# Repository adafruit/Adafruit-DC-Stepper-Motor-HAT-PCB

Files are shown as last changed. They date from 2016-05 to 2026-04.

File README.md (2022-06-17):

## Adafruit DC Stepper Motor HAT and Bonnet PCB
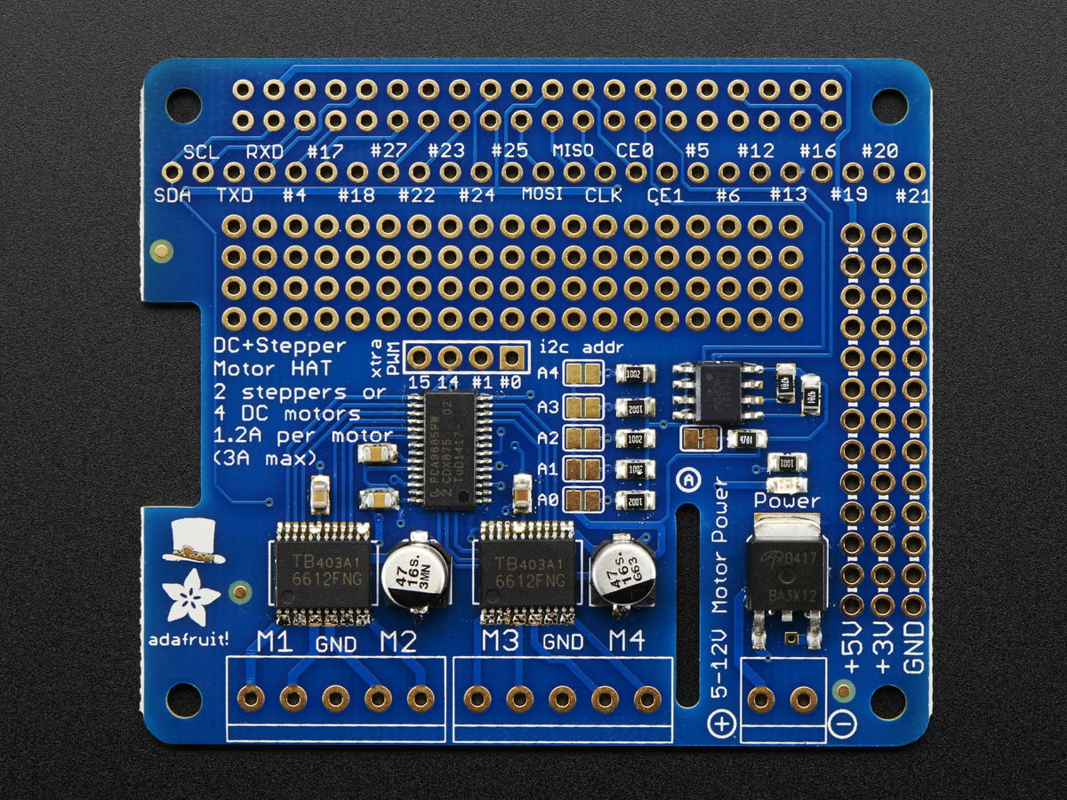
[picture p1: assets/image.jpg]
<a href="http://www.adafruit.com/products/2348"><br/>
Click here to purchase one from the Adafruit shop</a>

Let your robotic dreams come true with the new DC+Stepper Motor HAT from Adafruit. This Raspberry Pi add-on is perfect for any motion project as it can drive up to 4 DC or 2 Stepper motors with full PWM speed control.

Raspberry Pi and motors are not included. Works with any and all Raspberry Pi computers with 2x20 connection port.

Since the Raspberry Pi does not have a lot of PWM pins, we use a fully-dedicated PWM driver chip onboard to both control motor direction and speed. This chip handles all the motor and speed controls over I2C. Only two pins (SDA & SCL) are required to drive the multiple motors, and since it's I2C you can also connect any other I2C devices or HATs to the same pins.

In fact, you can even stack multiple Motor HATs, up to 32 of them, for controlling up to 64 stepper motors or 128 DC motors (or a mix of the two) - just remember to purchase and solder in a stacking header instead of the one we include.

Motors are controlled by TB6612 MOSFET drivers with 1.2A per channel current capability (you can draw up to 3A peak for approx 20ms at a time), a big improvement over L293D drivers and there are built-in flyback diodes as well.

PCB files for the Adafruit DC Stepper Motor Hat and Bonnet. The format is EagleCAD schematic and board layout
- https://www.adafruit.com/products/2348
- https://www.adafruit.com/product/4280

### License

Adafruit invests time and resources providing this open source design, please support Adafruit and open-source hardware by purchasing products from [Adafruit](https://www.adafruit.com)!

All text above must be included in any redistribution

Designed by Limor Fried/Ladyada for Adafruit Industries.
Creative Commons Attribution/Share-Alike, all text above must be included in any redistribution. 
See license.txt for additional information.

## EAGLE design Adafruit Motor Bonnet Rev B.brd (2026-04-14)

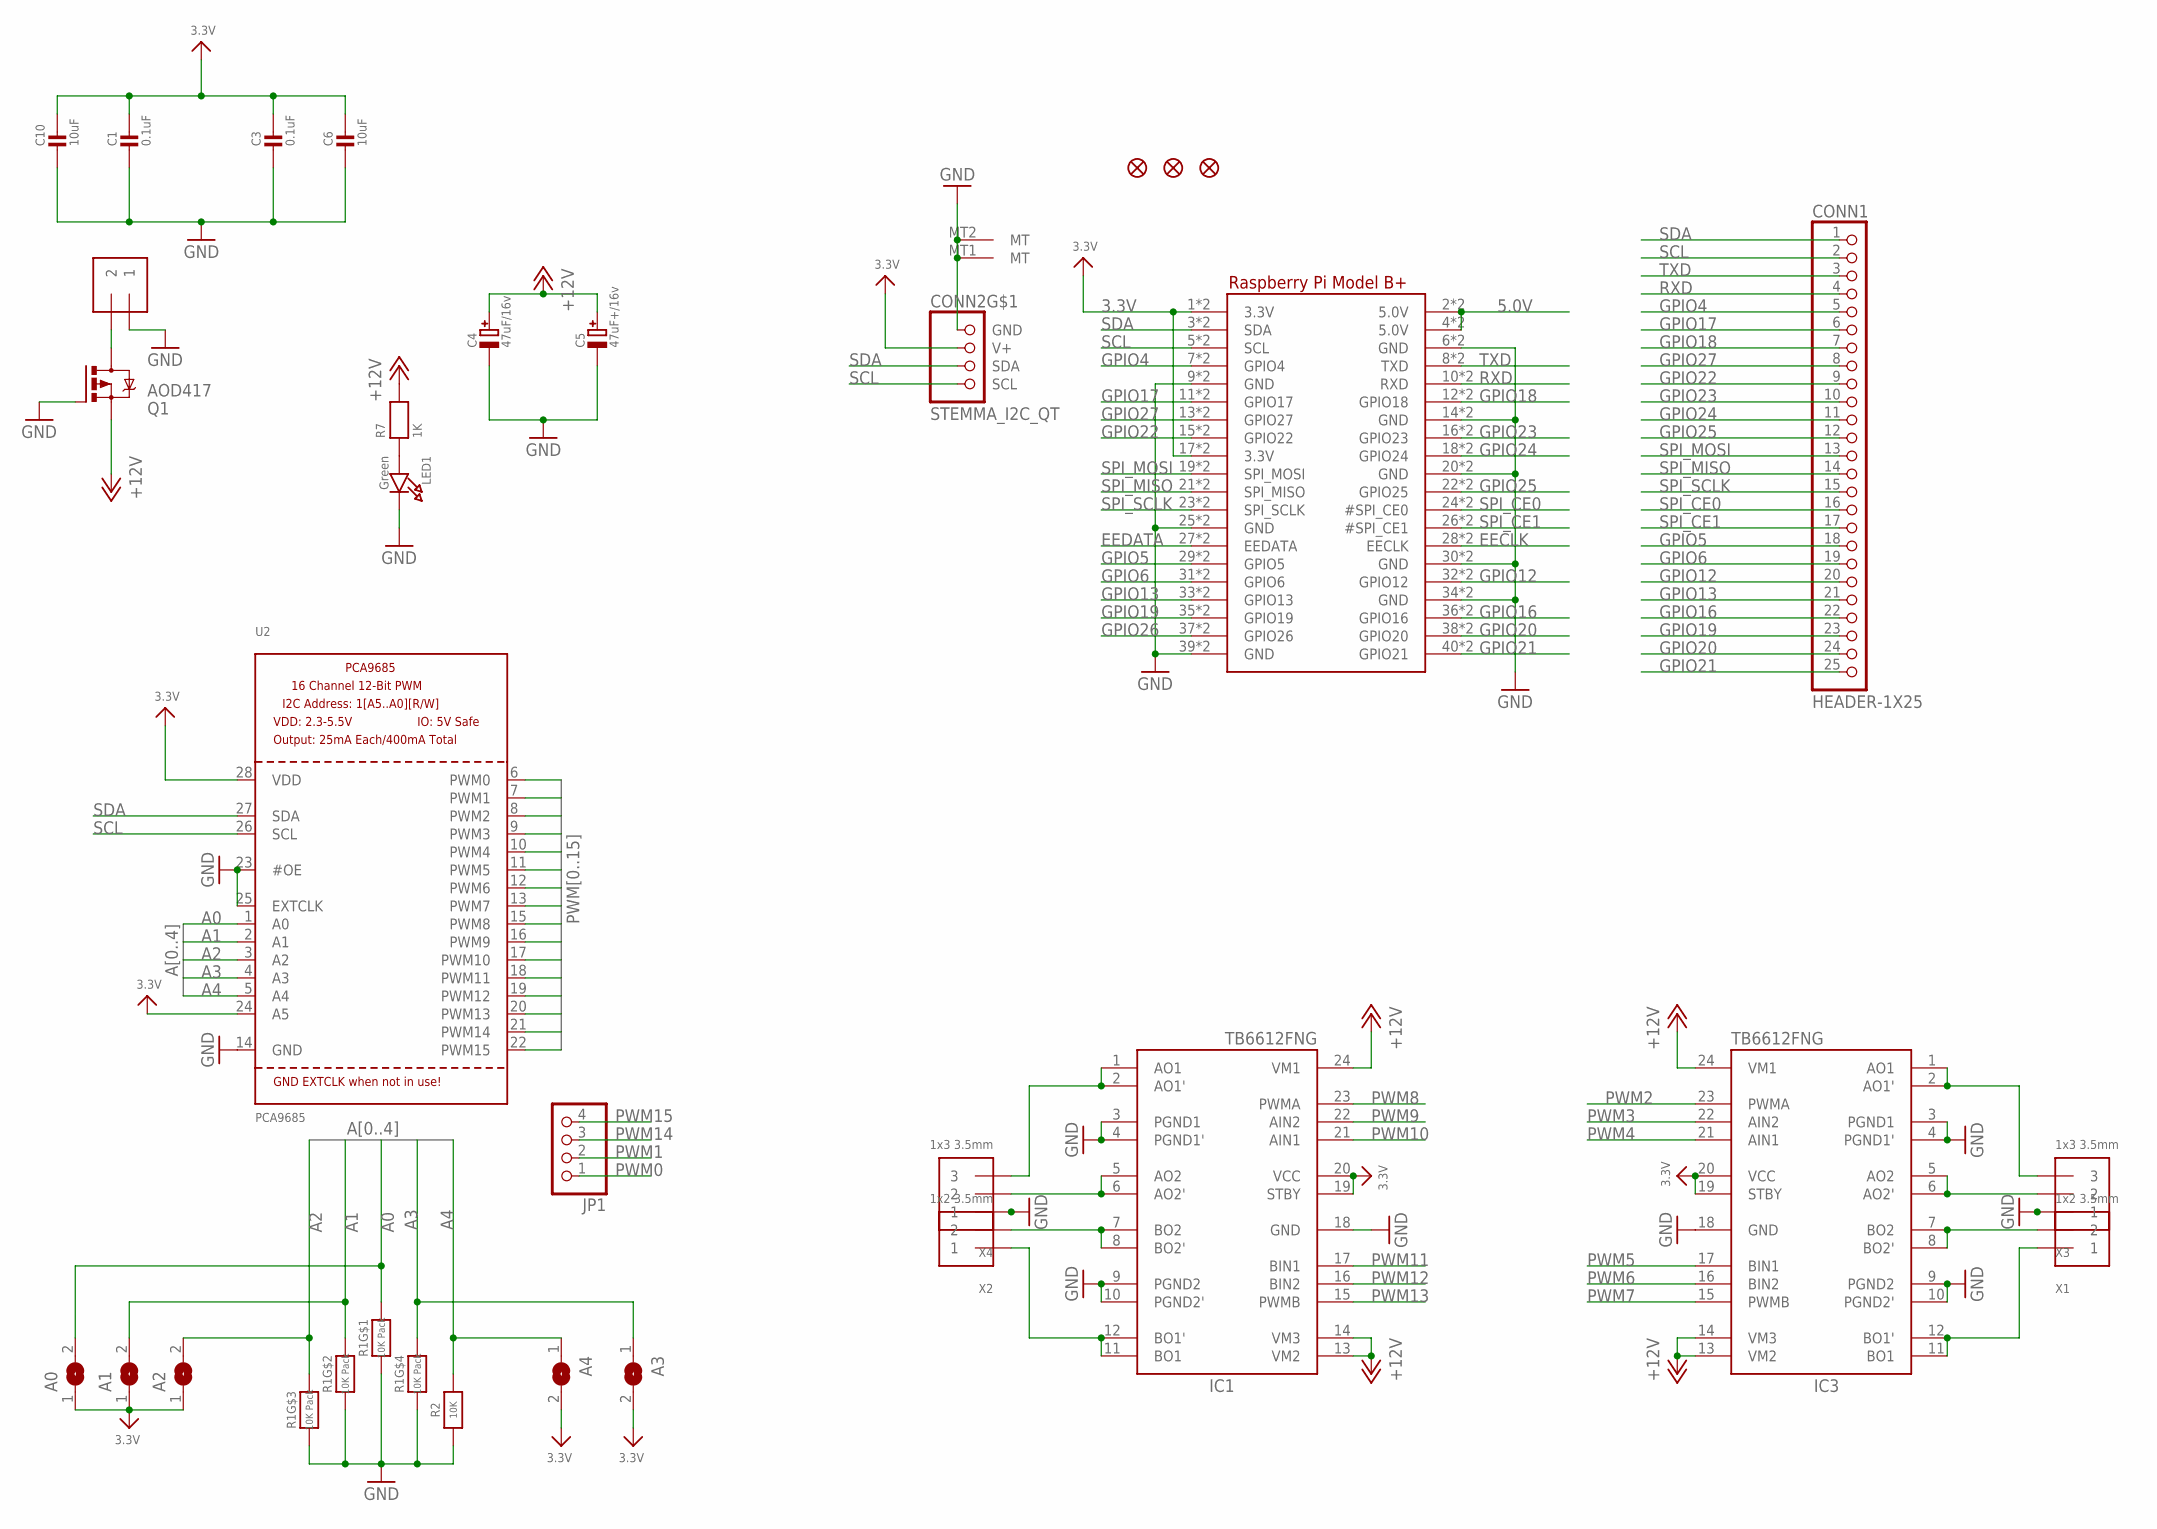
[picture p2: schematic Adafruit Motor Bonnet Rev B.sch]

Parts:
A0, A1, A2, A3, A4: SOLDERJUMPERREFLOW_NOPASTE; SOLDERJUMPER_REFLOW_NOPASTE
C1, C3: 0.1uF; 0603-NO
C4: 47uF/16v; PANASONIC_C
C5: 47uF+/16v; PANASONIC_C
C6, C10: 10uF; 0805-NO
CONN1: HEADER-1X25; 1X25_ROUND_70MIL
CONN2: STEMMA_I2C_QT; JST_SH4
FID1, FID2, FID3: FIDUCIAL_1MM
IC1, IC3: TB6612FNG; SSOP24
JP1: HEADER-1X4ROUND; 1X04_ROUND
LED1: Green; CHIPLED_0805_NOOUTLINE
MPOWER: 1x2 3.5mm; TERMBLOCK_1X2-3.5MM
Q1: AOD417; D-PAK_TO252AA
R1: 10K Pack; RESPACK_4X0603
R2: 10K; 0603-NO
R7: 1K; 0603-NO
RPI1: RASPBERRYPI_BPLUS_BONNET_THMSMT; PI_BONNET_THMSMT
U2: PCA9685; TSSOP28
X1, X2: 1x2 3.5mm; TERMBLOCK_1X2-3.5MM
X3, X4: 1x3 3.5mm; TERMBLOCK_1X3-3.5MM

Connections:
3.3V: A0.1, A1.1, A2.1, A3.2, A4.2, C1.1, C3.1, C6.1, C10.1, CONN2.2 (V+), IC1.19 (STBY), IC1.20 (VCC), IC3.19 (STBY), IC3.20 (VCC), RPI1.1 (3.3V), RPI1.17 (3.3V), RPI1.S1 (3.3V), RPI1.S17 (3.3V), U2.24 (A5), U2.28 (VDD)
5.0V: RPI1.2 (5.0V), RPI1.4 (5.0V), RPI1.S2 (5.0V), RPI1.S4 (5.0V)
+12V: C4.+, C5.+, IC1.13 (VM2), IC1.14 (VM3), IC1.24 (VM1), IC3.13 (VM2), IC3.14 (VM3), IC3.24 (VM1), Q1.3 (S), R7.2
A0: A0.2, R1.8 (2), U2.1 (A0)
A1: A1.2, R1.7 (2), U2.2 (A1)
A2: A2.2, R1.6 (2), U2.3 (A2)
A3: A3.1, R1.5 (2), U2.4 (A3)
A4: A4.1, R2.2, U2.5 (A4)
EECLK: RPI1.28 (EECLK), RPI1.S28 (EECLK)
EEDATA: RPI1.27 (EEDATA), RPI1.S27 (EEDATA)
GND: C1.2, C3.2, C4.-, C5.-, C6.2, C10.2, CONN2.1 (GND), CONN2.MT1 (MT), CONN2.MT2 (MT), IC1.3 (PGND1), IC1.4 (PGND1'), IC1.9 (PGND2), IC1.10 (PGND2'), IC1.18 (GND), IC3.3 (PGND1), IC3.4 (PGND1'), IC3.9 (PGND2), IC3.10 (PGND2'), IC3.18 (GND), LED1.C, MPOWER.1, Q1.1 (G), R1.1, R1.2 (1), R1.3 (1), R1.4 (1), R2.1, RPI1.6 (GND), RPI1.9 (GND), RPI1.14 (GND), RPI1.20 (GND), RPI1.25 (GND), RPI1.30 (GND), RPI1.34 (GND), RPI1.39 (GND), RPI1.S6 (GND), RPI1.S9 (GND), RPI1.S14 (GND), RPI1.S20 (GND), RPI1.S25 (GND), RPI1.S30 (GND), RPI1.S34 (GND), RPI1.S39 (GND), U2.14 (GND), U2.23 (#OE), U2.25 (EXTCLK), X3.1, X4.1
GPIO4: CONN1.5, RPI1.7 (GPIO4), RPI1.S7 (GPIO4)
GPIO5: CONN1.18, RPI1.29 (GPIO5), RPI1.S29 (GPIO5)
GPIO6: CONN1.19, RPI1.31 (GPIO6), RPI1.S31 (GPIO6)
GPIO12: CONN1.20, RPI1.32 (GPIO12), RPI1.S32 (GPIO12)
GPIO13: CONN1.21, RPI1.33 (GPIO13), RPI1.S33 (GPIO13)
GPIO16: CONN1.22, RPI1.36 (GPIO16), RPI1.S36 (GPIO16)
GPIO17: CONN1.6, RPI1.11 (GPIO17), RPI1.S11 (GPIO17)
GPIO18: CONN1.7, RPI1.12 (GPIO18), RPI1.S12 (GPIO18)
GPIO19: CONN1.23, RPI1.35 (GPIO19), RPI1.S35 (GPIO19)
GPIO20: CONN1.24, RPI1.38 (GPIO20), RPI1.S38 (GPIO20)
GPIO21: CONN1.25, RPI1.40 (GPIO21), RPI1.S40 (GPIO21)
GPIO22: CONN1.9, RPI1.15 (GPIO22), RPI1.S15 (GPIO22)
GPIO23: CONN1.10, RPI1.16 (GPIO23), RPI1.S16 (GPIO23)
GPIO24: CONN1.11, RPI1.18 (GPIO24), RPI1.S18 (GPIO24)
GPIO25: CONN1.12, RPI1.22 (GPIO25), RPI1.S22 (GPIO25)
GPIO26: RPI1.37 (GPIO26), RPI1.S37 (GPIO26)
GPIO27: CONN1.8, RPI1.13 (GPIO27), RPI1.S13 (GPIO27)
M1A: IC1.1 (AO1), IC1.2 (AO1'), X4.3
M1B: IC1.5 (AO2), IC1.6 (AO2'), X4.2
M2A: IC1.11 (BO1), IC1.12 (BO1'), X2.1
M2B: IC1.7 (BO2), IC1.8 (BO2'), X2.2
M3A: IC3.1 (AO1), IC3.2 (AO1'), X3.3
M3B: IC3.5 (AO2), IC3.6 (AO2'), X3.2
M4A: IC3.11 (BO1), IC3.12 (BO1'), X1.1
M4B: IC3.7 (BO2), IC3.8 (BO2'), X1.2
unnamed: LED1.A, R7.1
PWM0: JP1.1, U2.6 (PWM0)
PWM1: JP1.2, U2.7 (PWM1)
PWM2: IC3.23 (PWMA), U2.8 (PWM2)
PWM3: IC3.22 (AIN2), U2.9 (PWM3)
PWM4: IC3.21 (AIN1), U2.10 (PWM4)
PWM5: IC3.17 (BIN1), U2.11 (PWM5)
PWM6: IC3.16 (BIN2), U2.12 (PWM6)
PWM7: IC3.15 (PWMB), U2.13 (PWM7)
PWM8: IC1.23 (PWMA), U2.15 (PWM8)
PWM9: IC1.22 (AIN2), U2.16 (PWM9)
PWM10: IC1.21 (AIN1), U2.17 (PWM10)
PWM11: IC1.17 (BIN1), U2.18 (PWM11)
PWM12: IC1.16 (BIN2), U2.19 (PWM12)
PWM13: IC1.15 (PWMB), U2.20 (PWM13)
PWM14: JP1.3, U2.21 (PWM14)
PWM15: JP1.4, U2.22 (PWM15)
RXD: CONN1.4, RPI1.10 (RXD), RPI1.S10 (RXD)
SCL: CONN1.2, CONN2.4 (SCL), RPI1.5 (SCL), RPI1.S5 (SCL), U2.26 (SCL)
SDA: CONN1.1, CONN2.3 (SDA), RPI1.3 (SDA), RPI1.S3 (SDA), U2.27 (SDA)
SPI_CE0: CONN1.16, RPI1.24 (#SPI_CE0), RPI1.S24 (#SPI_CE0)
SPI_CE1: CONN1.17, RPI1.26 (#SPI_CE1), RPI1.S26 (#SPI_CE1)
SPI_MISO: CONN1.14, RPI1.21 (SPI_MISO), RPI1.S21 (SPI_MISO)
SPI_MOSI: CONN1.13, RPI1.19 (SPI_MOSI), RPI1.S19 (SPI_MOSI)
SPI_SCLK: CONN1.15, RPI1.23 (SPI_SCLK), RPI1.S23 (SPI_SCLK)
TXD: CONN1.3, RPI1.8 (TXD), RPI1.S8 (TXD)
VMOTOR: MPOWER.2, Q1.4 (D)

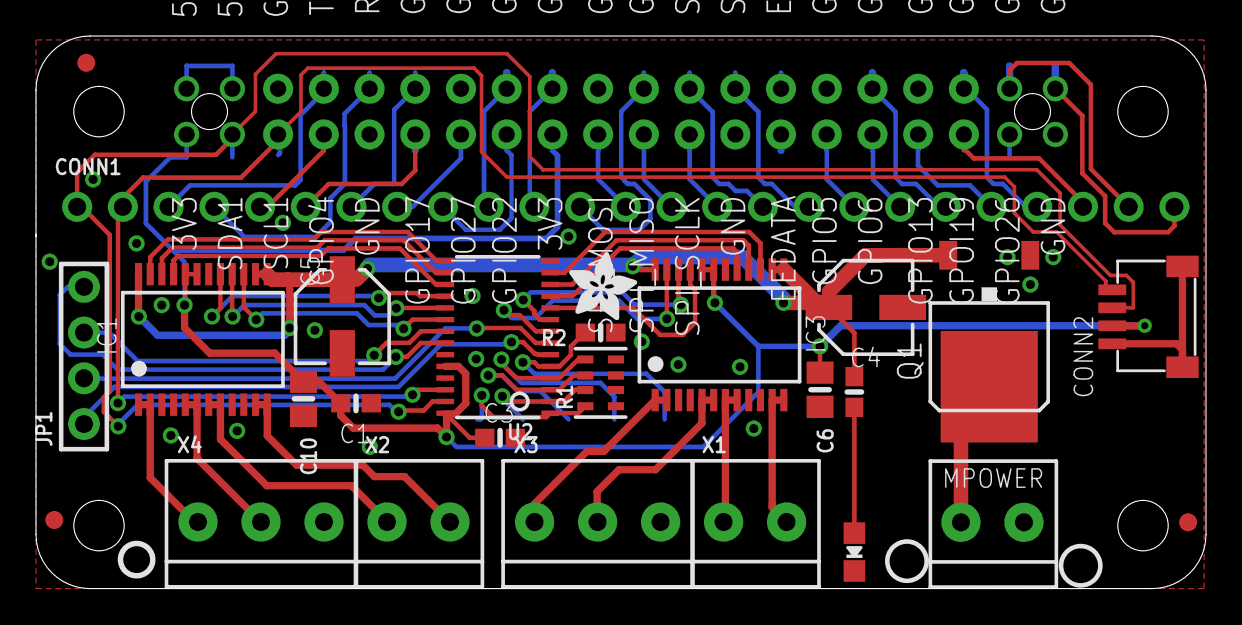
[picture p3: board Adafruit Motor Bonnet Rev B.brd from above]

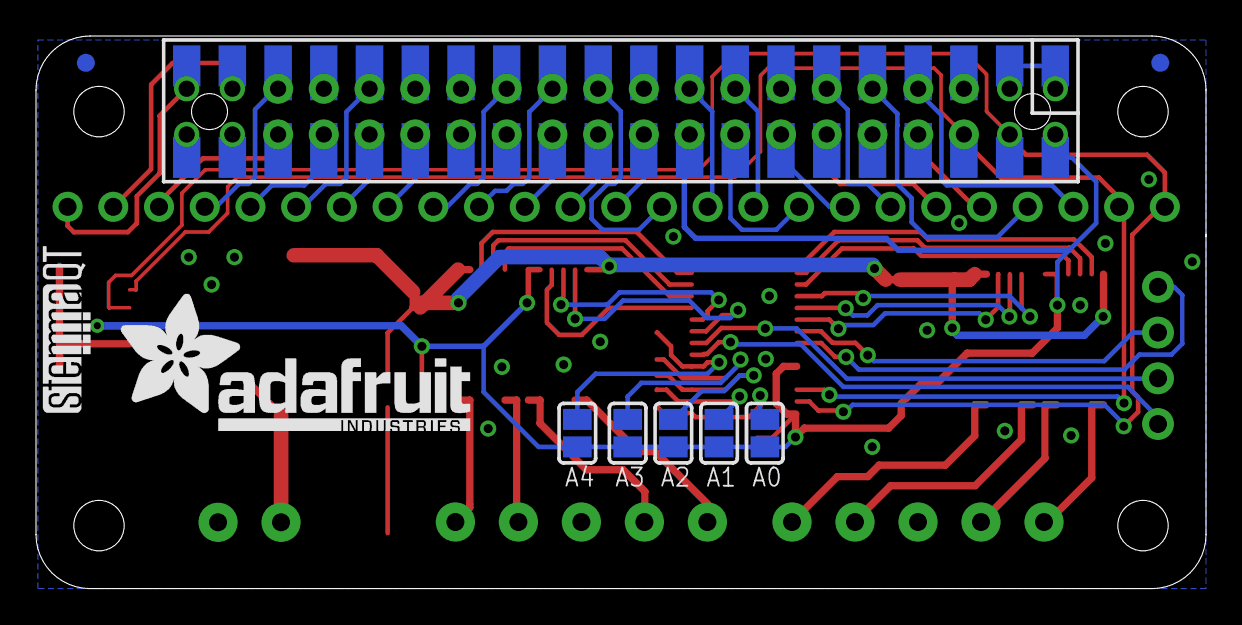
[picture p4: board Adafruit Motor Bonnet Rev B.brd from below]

Board: 2 copper layers, 65.0 x 30.7 mm, 82 parts (13 on the bottom side), 63 nets.

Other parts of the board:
PLABEL0: PLABEL0
PLABEL1: PLABEL1
PLABEL2: PLABEL2
PLABEL3: PLABEL3
PLABEL4: PLABEL4
PLABEL5: PLABEL5
PLABEL6: PLABEL6
PLABEL7: PLABEL7
PLABEL8: PLABEL8
PLABEL9: PLABEL9
PLABEL10: PLABEL10
PLABEL11: PLABEL11
PLABEL12: PLABEL12
PLABEL13: PLABEL13
PLABEL14: PLABEL14
PLABEL15: PLABEL15
PLABEL16: PLABEL16
PLABEL17: PLABEL17
PLABEL18: PLABEL18
PLABEL19: PLABEL19
PLABEL20: PLABEL20
PLABEL21: PLABEL21
PLABEL22: PLABEL22
PLABEL23: PLABEL23
PLABEL24: PLABEL24
PLABEL25: PLABEL25
PLABEL26: PLABEL26
PLABEL27: PLABEL27
PLABEL28: PLABEL28
PLABEL29: PLABEL29
PLABEL30: PLABEL30
PLABEL31: PLABEL31
PLABEL33: PLABEL33
PLABEL34: PLABEL34
PLABEL35: PLABEL35
PLABEL36: PLABEL36
PLABEL37: PLABEL37
PLABEL38: PLABEL38
PLABEL39: PLABEL39
PLABEL40: PLABEL40
PLABEL41: PLABEL41
PLABEL42: PLABEL42
PLABEL43: PLABEL43
PLABEL44: PLABEL44
PLABEL45: PLABEL45
PLABEL46: PLABEL46
PLABEL47: PLABEL47
U$6: PCBFEAT-REV-040
U$8: ADAFRUIT_TEXT_20MM
U$14: ADAFRUIT_3.5MM
U$15: STEMMAQT

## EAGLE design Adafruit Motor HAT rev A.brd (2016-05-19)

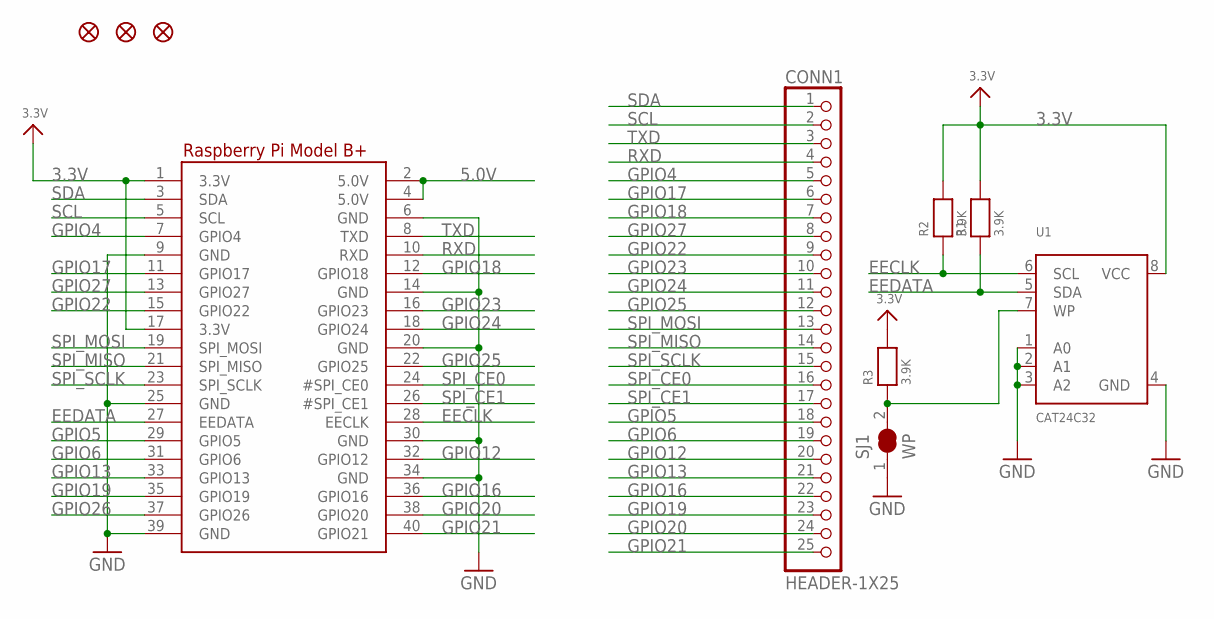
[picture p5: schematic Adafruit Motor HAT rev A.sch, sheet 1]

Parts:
CONN1: HEADER-1X25; 1X25_ROUND_70MIL
FID1, FID2, FID3: FIDUCIAL""; FIDUCIAL_1MM
R1, R2, R3: 3.9K; 0805-NO
RPI1: RASPBERRYPI_BPLUS_HATSLOTS; PI_HAT_SLOTS
SJ1: WP; SOLDERJUMPER_CLOSEDWIRE
U1: CAT24C32; SOIC8_150MIL

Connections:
3.3V: R1.2, R2.2, R3.2, RPI1.1 (3.3V), RPI1.17 (3.3V), U1.8 (VCC); also elsewhere on the board
5.0V: RPI1.2 (5.0V), RPI1.4 (5.0V)
EECLK: R2.1, RPI1.28 (EECLK), U1.6 (SCL)
EEDATA: R1.1, RPI1.27 (EEDATA), U1.5 (SDA)
GND: RPI1.6 (GND), RPI1.9 (GND), RPI1.14 (GND), RPI1.20 (GND), RPI1.25 (GND), RPI1.30 (GND), RPI1.34 (GND), RPI1.39 (GND), SJ1.1, U1.1 (A0), U1.2 (A1), U1.3 (A2), U1.4 (GND); also elsewhere on the board
GPIO4: CONN1.5, RPI1.7 (GPIO4)
GPIO5: CONN1.18, RPI1.29 (GPIO5)
GPIO6: CONN1.19, RPI1.31 (GPIO6)
GPIO12: CONN1.20, RPI1.32 (GPIO12)
GPIO13: CONN1.21, RPI1.33 (GPIO13)
GPIO16: CONN1.22, RPI1.36 (GPIO16)
GPIO17: CONN1.6, RPI1.11 (GPIO17)
GPIO18: CONN1.7, RPI1.12 (GPIO18)
GPIO19: CONN1.23, RPI1.35 (GPIO19)
GPIO20: CONN1.24, RPI1.38 (GPIO20)
GPIO21: CONN1.25, RPI1.40 (GPIO21)
GPIO22: CONN1.9, RPI1.15 (GPIO22)
GPIO23: CONN1.10, RPI1.16 (GPIO23)
GPIO24: CONN1.11, RPI1.18 (GPIO24)
GPIO25: CONN1.12, RPI1.22 (GPIO25)
GPIO26: RPI1.37 (GPIO26)
GPIO27: CONN1.8, RPI1.13 (GPIO27)
unnamed: R3.1, SJ1.2, U1.7 (WP)
RXD: CONN1.4, RPI1.10 (RXD)
SCL: CONN1.2, RPI1.5 (SCL); also elsewhere on the board
SDA: CONN1.1, RPI1.3 (SDA); also elsewhere on the board
SPI_CE0: CONN1.16, RPI1.24 (#SPI_CE0)
SPI_CE1: CONN1.17, RPI1.26 (#SPI_CE1)
SPI_MISO: CONN1.14, RPI1.21 (SPI_MISO)
SPI_MOSI: CONN1.13, RPI1.19 (SPI_MOSI)
SPI_SCLK: CONN1.15, RPI1.23 (SPI_SCLK)
TXD: CONN1.3, RPI1.8 (TXD)

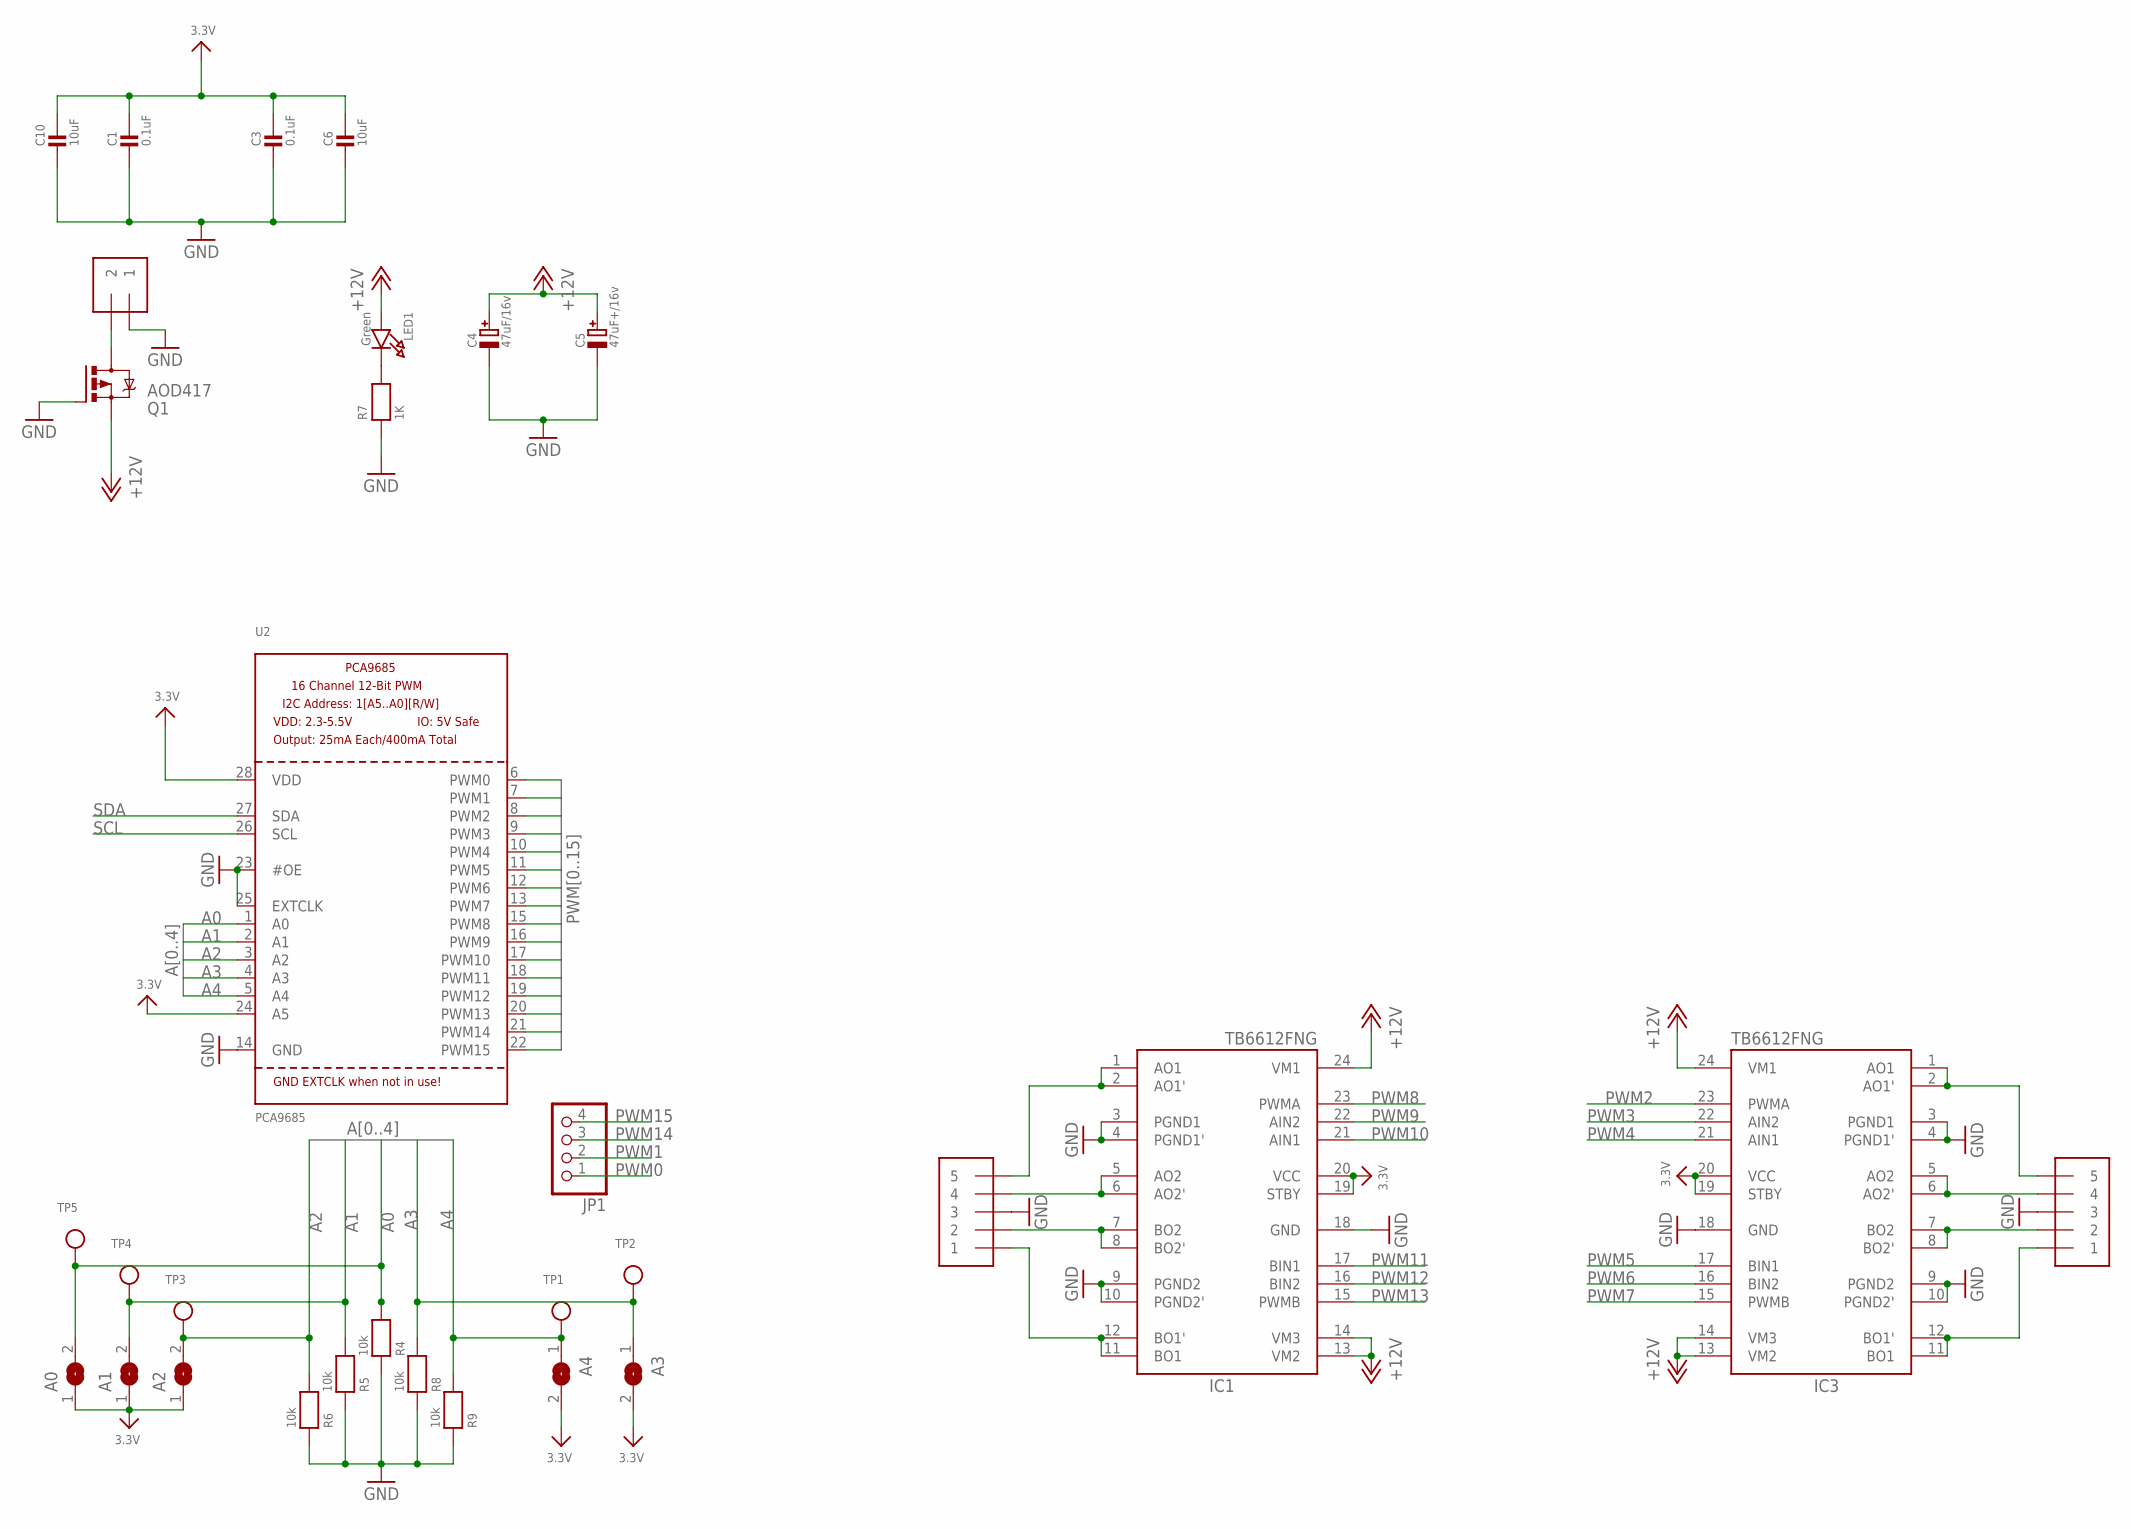
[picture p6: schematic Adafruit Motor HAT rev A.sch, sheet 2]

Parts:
A0, A1, A2, A3, A4: SOLDERJUMPERREFLOW_NOPASTE; SOLDERJUMPER_REFLOW_NOPASTE
C1, C3: 0.1uF; 0805-NO
C4: 47uF/16v; PANASONIC_C
C5: 47uF+/16v; PANASONIC_C
C6, C10: 10uF; 0805-NO
IC1, IC3: TB6612FNG; SSOP24
J1, J3: 1X5; 1X05-3.5MM
JP1: HEADER-1X476MIL; 1X04_ROUND_76
LED1: Green; CHIPLED_0805_NOOUTLINE
MPOWER: 1X2-3.5MM
Q1: AOD417; D-PAK_TO252AA
R4, R5, R6, R8, R9: 10k; 0805-NO
R7: 1K; 0805-NO
TP1, TP2, TP3, TP4, TP5: TESTPOINTROUND2MM; TESTPOINT_ROUND_2MM
U2: PCA9685; TSSOP28

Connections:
3.3V: A0.1, A1.1, A2.1, A3.2, A4.2, C1.1, C3.1, C6.1, C10.1, IC1.19 (STBY), IC1.20 (VCC), IC3.19 (STBY), IC3.20 (VCC), U2.24 (A5), U2.28 (VDD); also elsewhere on the board
+12V: C4.+, C5.+, IC1.13 (VM2), IC1.14 (VM3), IC1.24 (VM1), IC3.13 (VM2), IC3.14 (VM3), IC3.24 (VM1), LED1.A, Q1.3 (S)
A0: A0.2, R4.2, TP5.P$1, U2.1 (A0)
A1: A1.2, R5.2, TP4.P$1, U2.2 (A1)
A2: A2.2, R6.2, TP3.P$1, U2.3 (A2)
A3: A3.1, R8.2, TP2.P$1, U2.4 (A3)
A4: A4.1, R9.2, TP1.P$1, U2.5 (A4)
GND: C1.2, C3.2, C4.-, C5.-, C6.2, C10.2, IC1.3 (PGND1), IC1.4 (PGND1'), IC1.9 (PGND2), IC1.10 (PGND2'), IC1.18 (GND), IC3.3 (PGND1), IC3.4 (PGND1'), IC3.9 (PGND2), IC3.10 (PGND2'), IC3.18 (GND), J1.3, J3.3, MPOWER.1, Q1.1 (G), R4.1, R5.1, R6.1, R7.1, R8.1, R9.1, U2.14 (GND), U2.23 (#OE), U2.25 (EXTCLK); also elsewhere on the board
unnamed: MPOWER.2, Q1.4 (D)
unnamed: IC1.1 (AO1), IC1.2 (AO1'), J1.5
unnamed: IC1.5 (AO2), IC1.6 (AO2'), J1.4
unnamed: IC1.7 (BO2), IC1.8 (BO2'), J1.2
unnamed: IC1.11 (BO1), IC1.12 (BO1'), J1.1
unnamed: IC3.1 (AO1), IC3.2 (AO1'), J3.5
unnamed: IC3.5 (AO2), IC3.6 (AO2'), J3.4
unnamed: IC3.7 (BO2), IC3.8 (BO2'), J3.2
unnamed: IC3.11 (BO1), IC3.12 (BO1'), J3.1
unnamed: LED1.C, R7.2
PWM0: JP1.1, U2.6 (PWM0)
PWM1: JP1.2, U2.7 (PWM1)
PWM2: IC3.23 (PWMA), U2.8 (PWM2)
PWM3: IC3.22 (AIN2), U2.9 (PWM3)
PWM4: IC3.21 (AIN1), U2.10 (PWM4)
PWM5: IC3.17 (BIN1), U2.11 (PWM5)
PWM6: IC3.16 (BIN2), U2.12 (PWM6)
PWM7: IC3.15 (PWMB), U2.13 (PWM7)
PWM8: IC1.23 (PWMA), U2.15 (PWM8)
PWM9: IC1.22 (AIN2), U2.16 (PWM9)
PWM10: IC1.21 (AIN1), U2.17 (PWM10)
PWM11: IC1.17 (BIN1), U2.18 (PWM11)
PWM12: IC1.16 (BIN2), U2.19 (PWM12)
PWM13: IC1.15 (PWMB), U2.20 (PWM13)
PWM14: JP1.3, U2.21 (PWM14)
PWM15: JP1.4, U2.22 (PWM15)
SCL: U2.26 (SCL); also elsewhere on the board
SDA: U2.27 (SDA); also elsewhere on the board

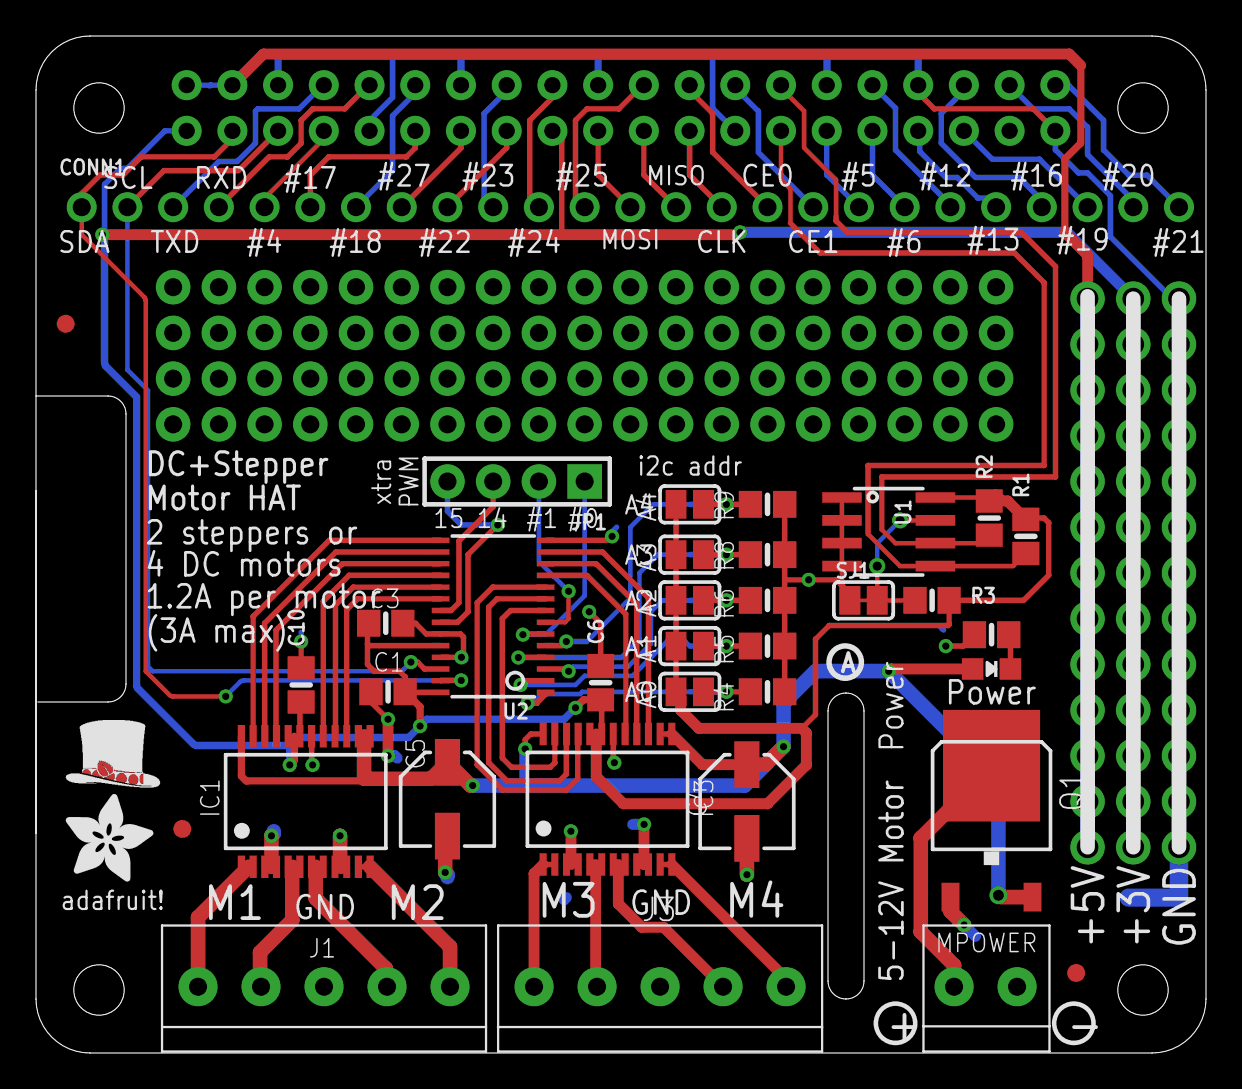
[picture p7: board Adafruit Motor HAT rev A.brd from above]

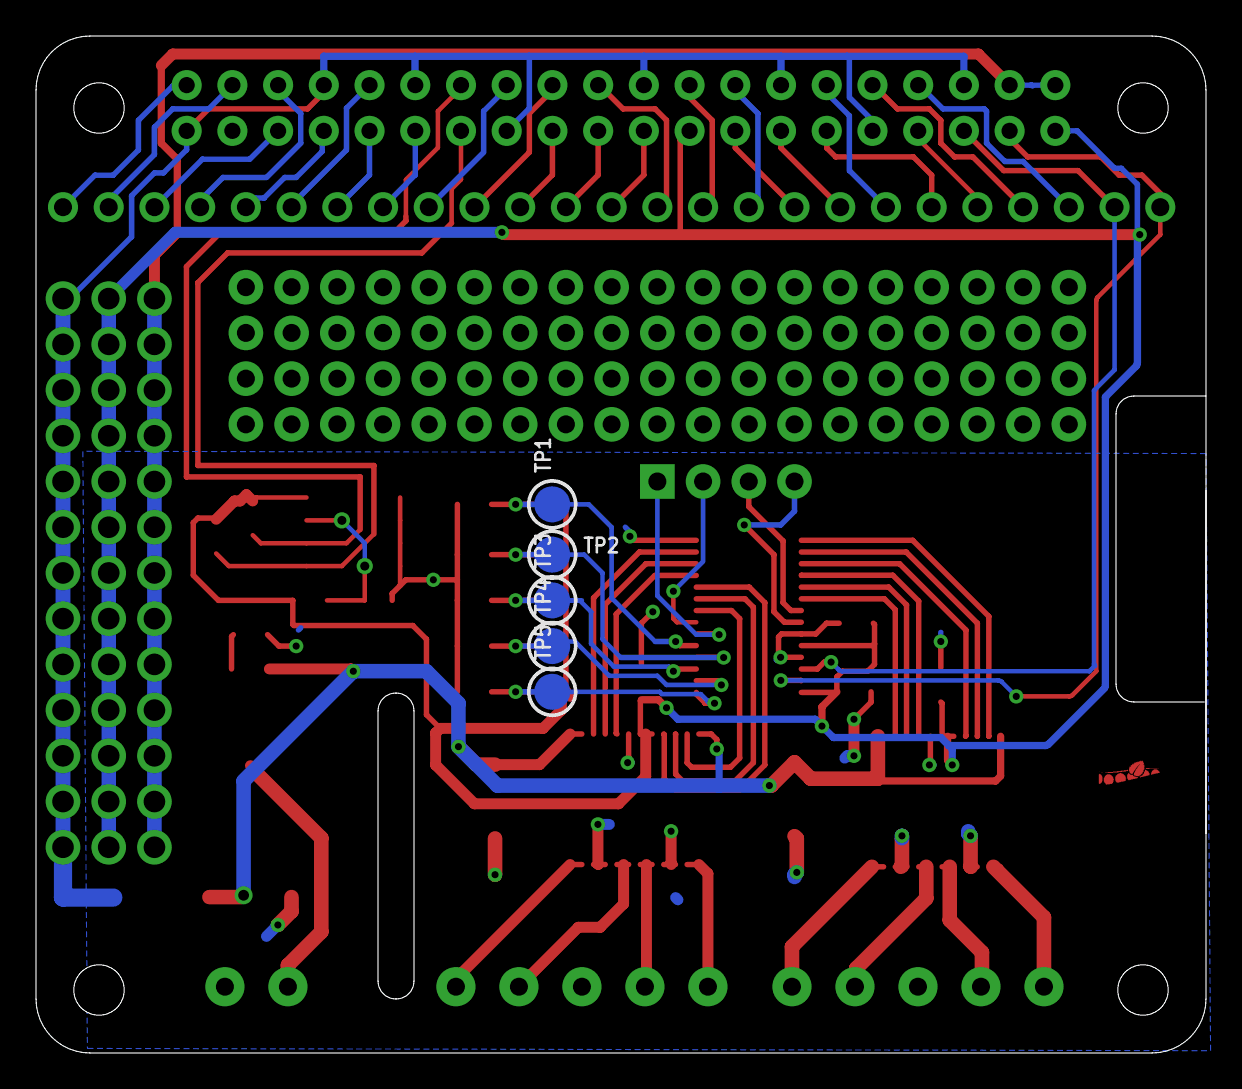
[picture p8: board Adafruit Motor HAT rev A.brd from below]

Board: 2 copper layers, 65.0 x 56.5 mm, 44 parts (5 on the bottom side), 63 nets.

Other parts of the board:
U$5: PIHATLOGO
U$6: PCBFEAT-REV-040
U$51: ADAFRUIT_5MM

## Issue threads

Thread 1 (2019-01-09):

GPIO26

jexoteric, 2019-01-09:
Is GPIO26 (physical pin 37) left out of the breakout on purpose? Was this purely because of space, or is there a different reason not have it broken out on the board?

ladyada, 2019-01-09:
no space is all :)

Closed 2019-01-09.

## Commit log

2022-06-17 Added Motor Bonnet files
    [Adafruit Motor Bonnet Rev A.brd, Adafruit Motor Bonnet Rev A.sch]
2026-04-14 add bonnet rev b
    [Adafruit Motor Bonnet Rev B.brd, Adafruit Motor Bonnet Rev B.sch]

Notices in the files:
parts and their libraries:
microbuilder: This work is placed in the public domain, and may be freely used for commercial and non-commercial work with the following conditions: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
